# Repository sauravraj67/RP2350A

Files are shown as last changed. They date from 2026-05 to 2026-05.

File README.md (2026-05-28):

# RP2350A

I made a custom RP2350A devboard  , it has a USB type C and i tried to keep the size of the board as small as possible and to have as much as useful pins available on the board..
<br>


<br>
## Overview
This project is a **compact 2-layer development board** based on the **Rp2350A**. It exposes **all usable GPIOs**, includes onboard **3.3V regulation**, and USB connectivity for easy programming and prototyping. 

## Features
- RP2350A Chip 
- 2-layer compact PCB
- USB connection for programming and power
- Onboard 3.3V voltage regulation

- ## Bill of Materials (BOM)
- 
| Qty | Description |  Total (USD) |
|----|---|---|
| 1 | PCB and Assembly  | 68.89  	 |
| 1 |Shipping JLCPCB - Discount  | 1.72 |

### 💰 Cost Summary
 
- **Estimated Total Cost:** **$70.61 USD**

## Schematic & PCB



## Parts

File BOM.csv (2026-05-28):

Item | Price | Source
PCB and Assembly | 68.89 | JLCPCB
Shipping JLCPCB - Discount | 1.72 | JLCPCB
Total | 70.61 | JLCPCB

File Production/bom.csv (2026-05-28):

Designator | Footprint | Quantity | Value | LCSC Part #
C1, C19, C5 | 0805 | 3 | 10u
C10, C6, C7, C9 | 0805 | 4 | 4.7u
C11, C12, C13, C14, C15, C16, C17, C18, C8 | 0805 | 9 | 100n
C3, C4 | 0805 | 2 | 15p
J1 | 2171790001_MOL | 1 | 2171790001
J5, J6 | PinHeader_1x22_P2.54mm_Vertical | 2 | Conn_01x22
L1 | INDC2016X100N | 1 | 3.3u
R2, R4, R6 | 0805 | 3 | 1k
R3, R9 | 0805 | 2 | 5.1k
R5 | 0805 | 1 | 33
R7, R8 | 0805 | 2 | 27
SW1, SW2 | Button_CnK_PTS636.0_6x3.5mm | 2 | SW_Push
U1 | RP2350-QFN-60-1EP_7x7_P0.4mm_EP3.4x3.4mm_ThermalVias | 1 | RP2350_60QFN
U2 | SOT-223-3_TabPin2 | 1 | NCP1117-3.3_SOT223
Y1 | Crystal_SMD_3225-4Pin_3.2x2.5mm | 1 | ABM8-272-T3

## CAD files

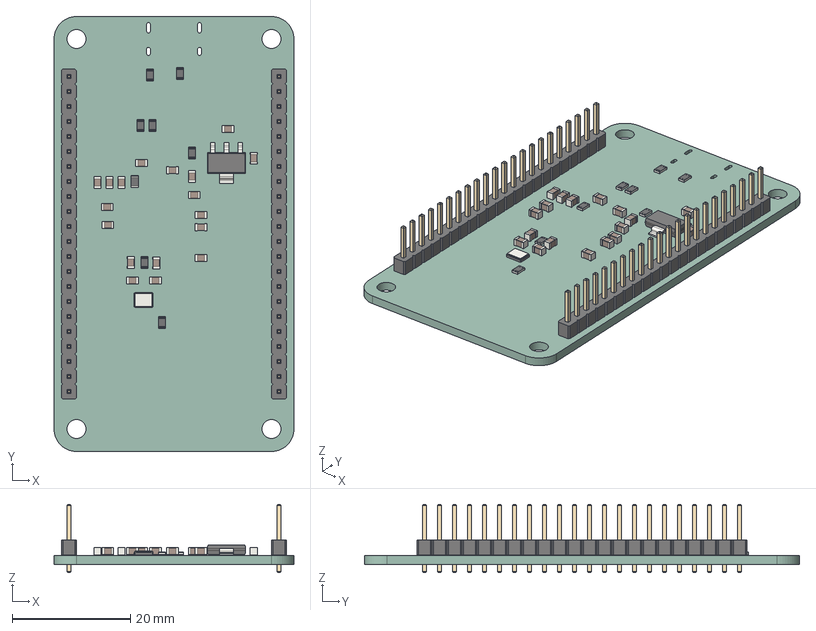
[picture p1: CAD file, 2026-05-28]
CAD/RP2354A-dev.step
40.6 x 73.7 x 11.5 mm
C_0805_2012Metric x 18
SOT-223
R_0805_2012Metric x 8
PinHeader_1x22_P2.54mm_Vertical x 2
Crystal_SMD_3225-4Pin_3.2x2.5mm
RP2354A-dev_PCB

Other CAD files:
CAD/RP2354A-dev.f3d

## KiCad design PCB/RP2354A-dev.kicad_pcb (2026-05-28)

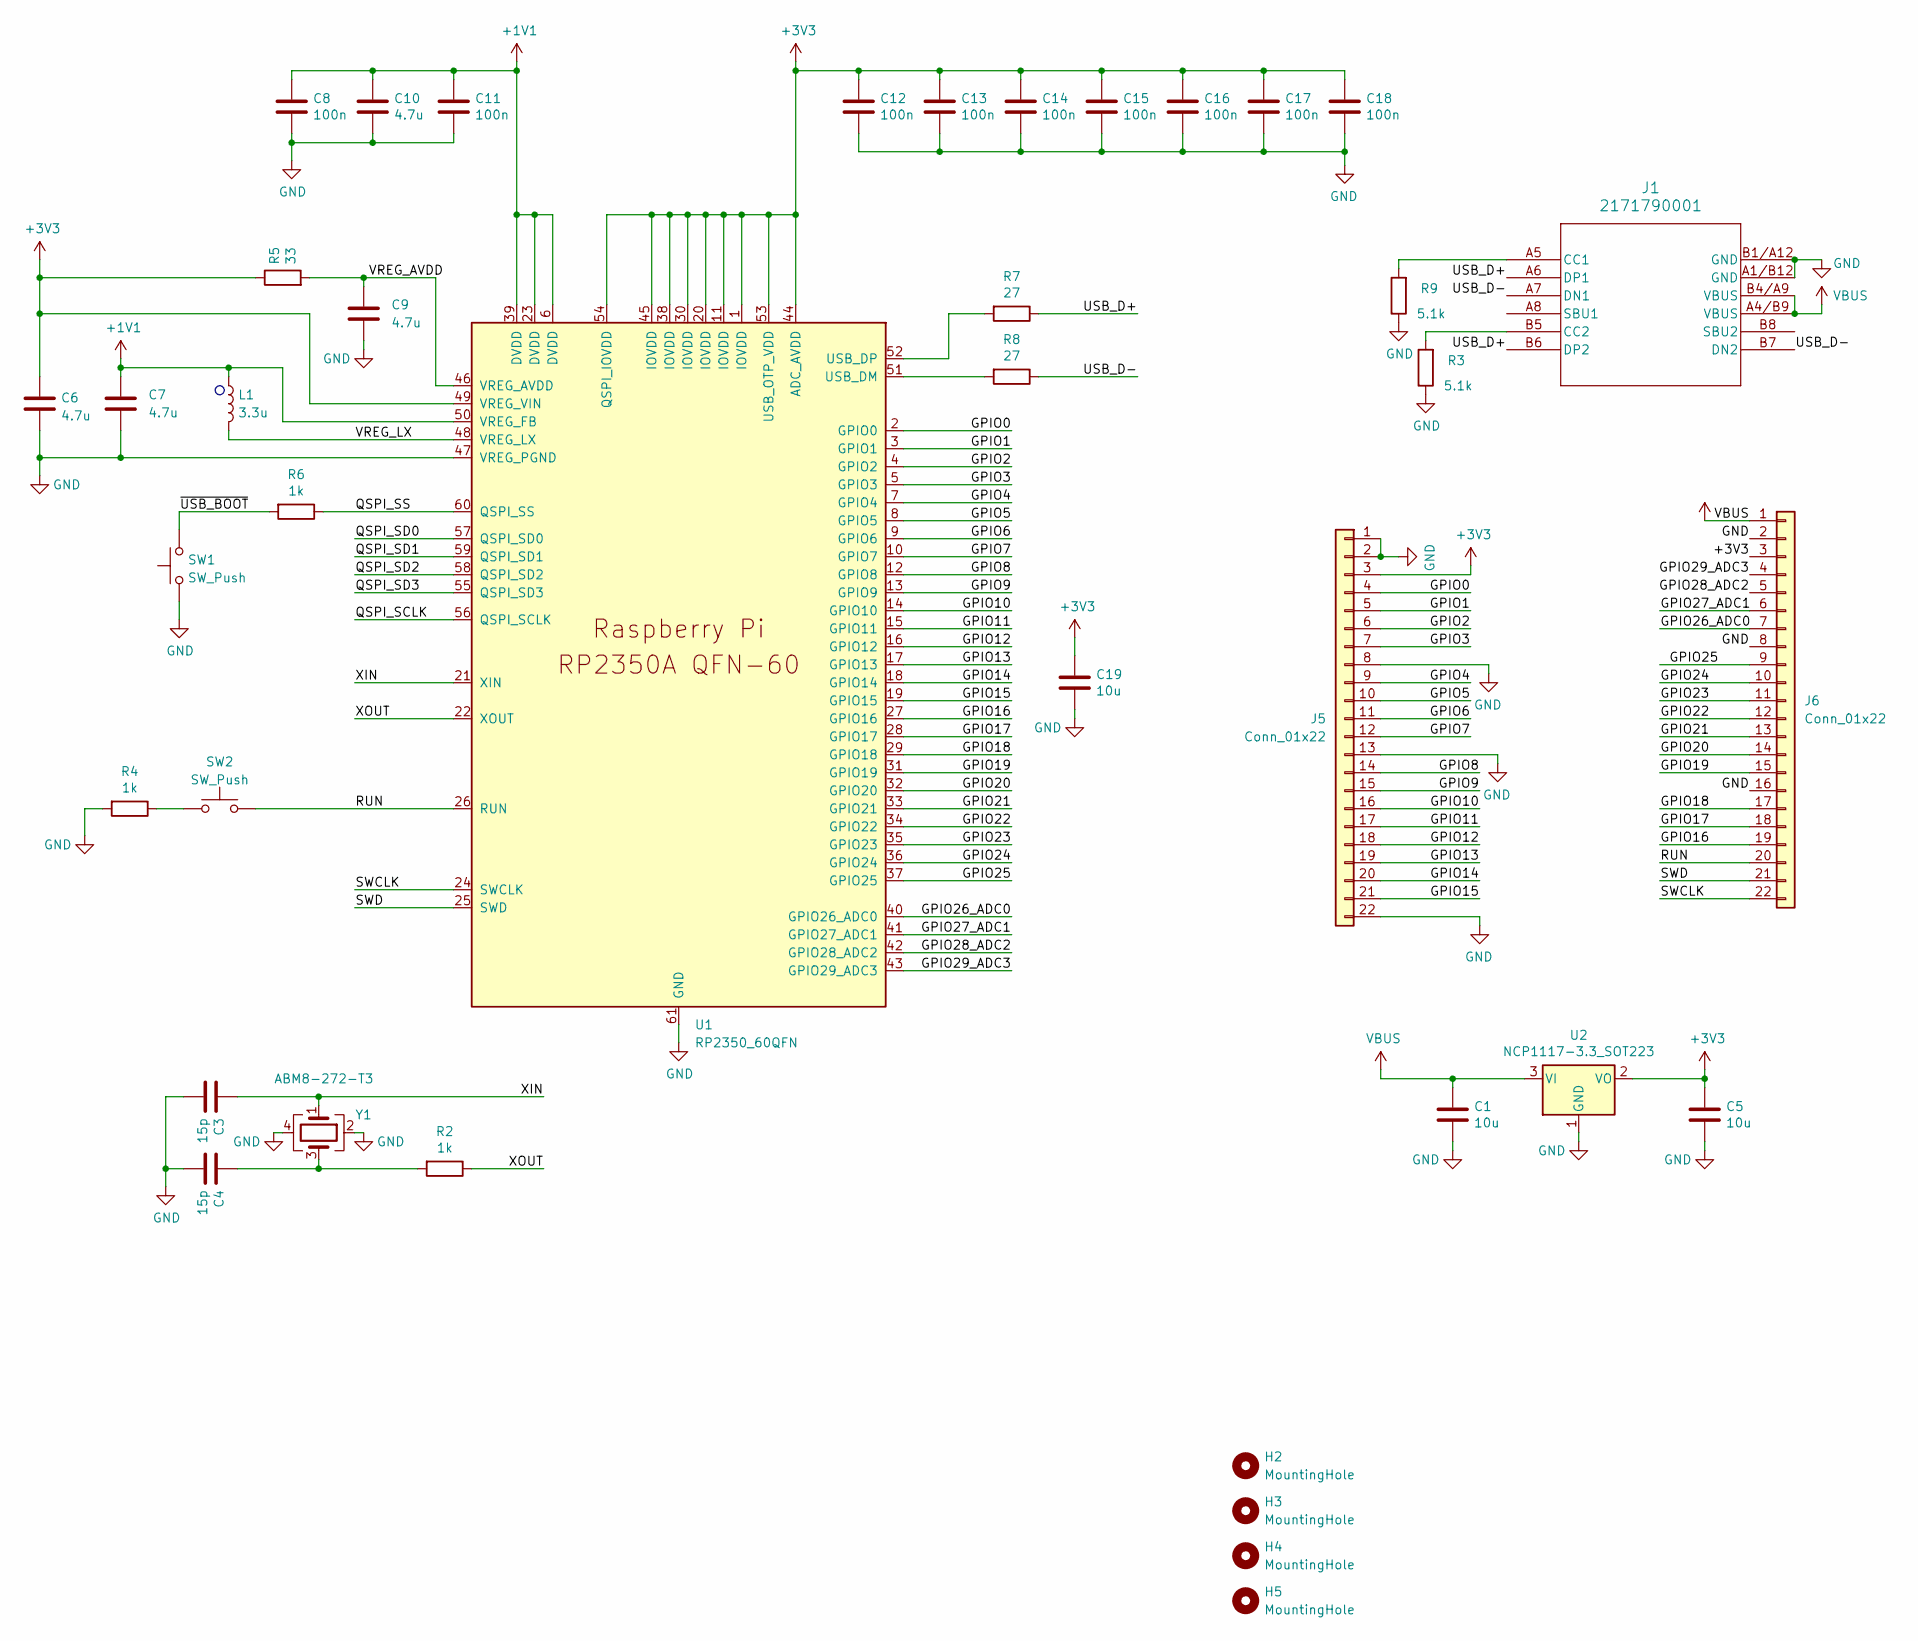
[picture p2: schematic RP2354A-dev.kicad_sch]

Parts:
C1, C5, C19: 10u; C_0805_2012Metric
C3, C4: 15p; C_0805_2012Metric
C6, C7, C9, C10: 4.7u; C_0805_2012Metric
C8, C11, C12, C13, C14, C15, C16, C17, C18: 100n; C_0805_2012Metric
H2, H3, H4, H5: MountingHole; MountingHole_3.2mm_M3
J1: 2171790001; 2171790001_MOL
J5, J6: Conn_01x22; PinHeader_1x22_P2.54mm_Vertical
L1: 3.3u; INDC2016X100N
R2, R4, R6: 1k; R_0805_2012Metric
R3, R9: 5.1k; R_0805_2012Metric
R5: 33; R_0805_2012Metric
R7, R8: 27; R_0805_2012Metric
SW1, SW2: SW_Push; Button_CnK_PTS636.0_6x3.5mm
U1: RP2350_60QFN; RP2350-QFN-60-1EP_7x7_P0.4mm_EP3.4x3.4mm_ThermalVias
U2: NCP1117-3.3_SOT223; SOT-223-3_TabPin2
Y1: ABM8-272-T3; Crystal_SMD_3225-4Pin_3.2x2.5mm

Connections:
+1V1: C7.1, C8.1, C10.1, C11.1, L1.1, U1.6 (DVDD), U1.23 (DVDD), U1.39 (DVDD), U1.50 (VREG_FB)
+3V3: C5.1, C6.1, C12.1, C13.1, C14.1, C15.1, C16.1, C17.1, C18.1, C19.1, J5.3, J6.3, R5.1, U1.1 (IOVDD), U1.11 (IOVDD), U1.20 (IOVDD), U1.30 (IOVDD), U1.38 (IOVDD), U1.44 (ADC_AVDD), U1.45 (IOVDD), U1.49 (VREG_VIN), U1.53 (USB_OTP_VDD), U1.54 (QSPI_IOVDD), U2.2 (VO)
/GPIO0: J5.4, U1.2 (GPIO0)
/GPIO1: J5.5, U1.3 (GPIO1)
/GPIO2: J5.6, U1.4 (GPIO2)
/GPIO3: J5.7, U1.5 (GPIO3)
/GPIO4: J5.9, U1.7 (GPIO4)
/GPIO5: J5.10, U1.8 (GPIO5)
/GPIO6: J5.11, U1.9 (GPIO6)
/GPIO7: J5.12, U1.10 (GPIO7)
/GPIO8: J5.14, U1.12 (GPIO8)
/GPIO9: J5.15, U1.13 (GPIO9)
/GPIO10: J5.16, U1.14 (GPIO10)
/GPIO11: J5.17, U1.15 (GPIO11)
/GPIO12: J5.18, U1.16 (GPIO12)
/GPIO13: J5.19, U1.17 (GPIO13)
/GPIO14: J5.20, U1.18 (GPIO14)
/GPIO15: J5.21, U1.19 (GPIO15)
/GPIO16: J6.19, U1.27 (GPIO16)
/GPIO17: J6.18, U1.28 (GPIO17)
/GPIO18: J6.17, U1.29 (GPIO18)
/GPIO19: J6.15, U1.31 (GPIO19)
/GPIO20: J6.14, U1.32 (GPIO20)
/GPIO21: J6.13, U1.33 (GPIO21)
/GPIO22: J6.12, U1.34 (GPIO22)
/GPIO23: J6.11, U1.35 (GPIO23)
/GPIO24: J6.10, U1.36 (GPIO24)
/GPIO25: J6.9, U1.37 (GPIO25)
/GPIO26_ADC0: J6.7, U1.40 (GPIO26_ADC0)
/GPIO27_ADC1: J6.6, U1.41 (GPIO27_ADC1)
/GPIO28_ADC2: J6.5, U1.42 (GPIO28_ADC2)
/GPIO29_ADC3: J6.4, U1.43 (GPIO29_ADC3)
/QSPI_SCLK: U1.56 (QSPI_SCLK)
/QSPI_SD0: U1.57 (QSPI_SD0)
/QSPI_SD1: U1.59 (QSPI_SD1)
/QSPI_SD2: U1.58 (QSPI_SD2)
/QSPI_SD3: U1.55 (QSPI_SD3)
/QSPI_SS: R6.1, U1.60 (QSPI_SS)
/RUN: J6.20, SW2.2, U1.26 (RUN)
/SWCLK: J6.22, U1.24 (SWCLK)
/SWD: J6.21, U1.25 (SWD)
/USB_D+: J1.A6 (DP1), J1.B6 (DP2), R7.1
/USB_D-: J1.A7 (DN1), J1.B7 (DN2), R8.1
/VREG_AVDD: C9.1, R5.2, U1.46 (VREG_AVDD)
/VREG_LX: L1.2, U1.48 (VREG_LX)
/XIN: C3.1, U1.21 (XIN), Y1.1
/XOUT: R2.1, U1.22 (XOUT)
/~USB_BOOT: R6.2, SW1.2
GND: C1.2, C3.2, C4.2, C5.2, C6.2, C7.2, C8.2, C9.2, C10.2, C11.2, C12.2, C13.2, C14.2, C15.2, C16.2, C17.2, C18.2, C19.2, J1.A1/B12 (GND), J1.B1/A12 (GND), J5.1, J5.2, J5.8, J5.13, J5.22, J6.2, J6.8, J6.16, R3.1, R4.2, R9.1, SW1.1, U1.47 (VREG_PGND), U1.61 (GND), U2.1 (GND), Y1.2, Y1.4
unnamed: C4.1, R2.2, Y1.3
unnamed: J1.A5 (CC1), R9.2
unnamed: J1.B5 (CC2), R3.2
unnamed: R4.1, SW2.1
unnamed: R8.2, U1.51 (USB_DM)
unnamed: R7.2, U1.52 (USB_DP)
VBUS: C1.1, J1.A4/B9 (VBUS), J1.B4/A9 (VBUS), J6.1, U2.3 (VI)

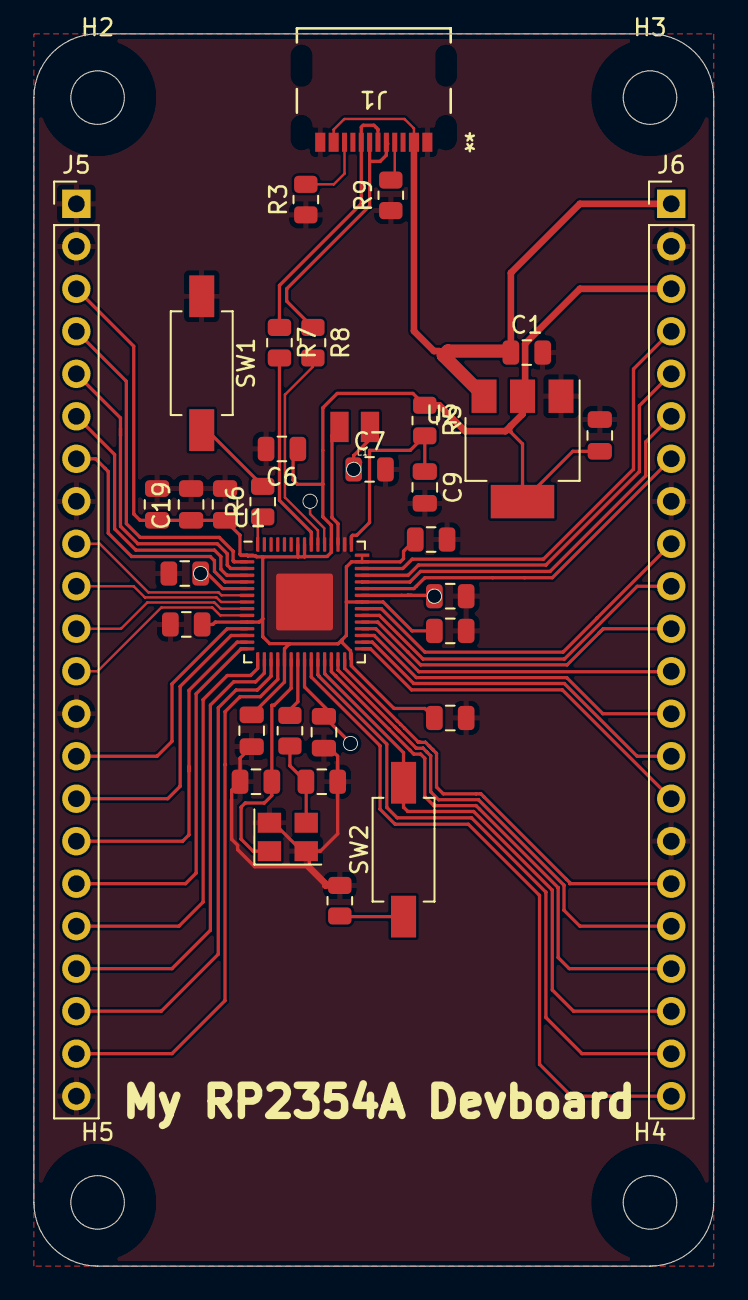
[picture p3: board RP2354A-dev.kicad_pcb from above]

Board: 2 copper layers, 40.6 x 73.7 mm, 39 parts (0 on the bottom side), 51 nets.
